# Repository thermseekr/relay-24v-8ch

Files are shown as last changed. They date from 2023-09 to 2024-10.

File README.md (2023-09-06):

# RELAY-24V-8CH

Relay board with 8x 24 VDC 10A relays. This board is designed to be used togheter with [ESP-24V-16CH](https://github.com/thermseekr/esp-24v-16ch) and [ESP-24V-32CH](https://github.com/thermseekr/esp-24v-32ch), but can be driven by any 24V control circuit compatible with NPN inputs.

The dimensions are such that the board can be mounted on a PCB DIN rail holder from the Brazilian manufacturer Metaltex, check [here](https://www.metaltex.com.br/produtos/componentes/suportes/sp7-suporte-para-montagem-de-placa-de-circuito-impresso-em-trilho-din) for details.

Board V1 uses Omron 16A relays and is limited to 12A/channel, board V2 uses Omron 10A relays and is limited to 8A/channel. The current limits are imposed per copper trace capacity.

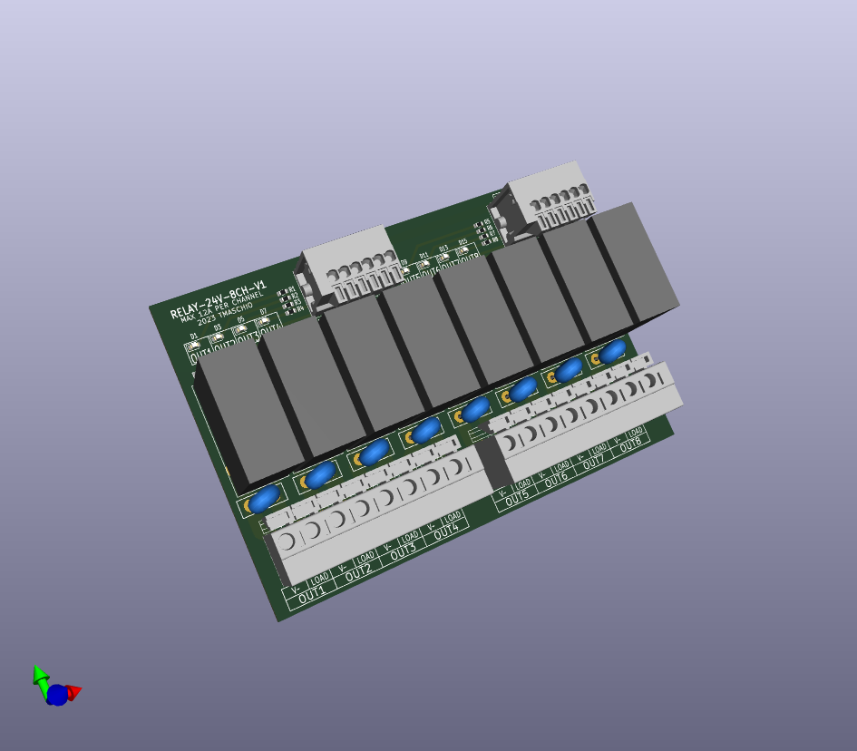
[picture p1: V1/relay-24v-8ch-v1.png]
RELAY-24V-8CH


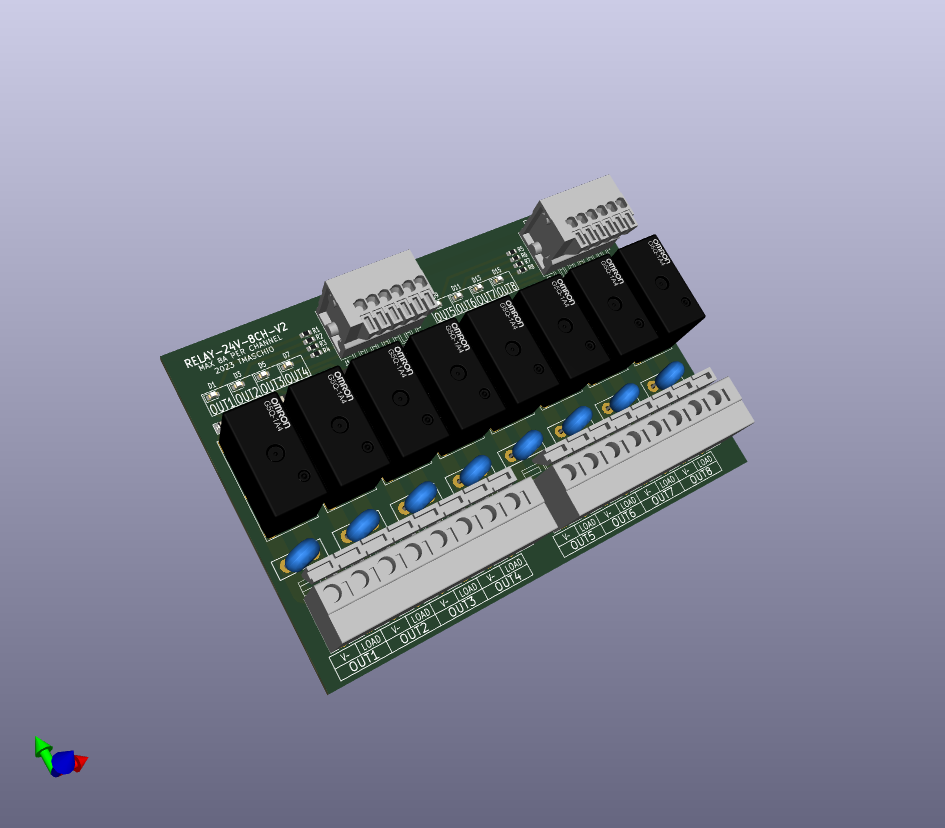
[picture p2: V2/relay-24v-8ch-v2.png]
RELAY-24V-8CH


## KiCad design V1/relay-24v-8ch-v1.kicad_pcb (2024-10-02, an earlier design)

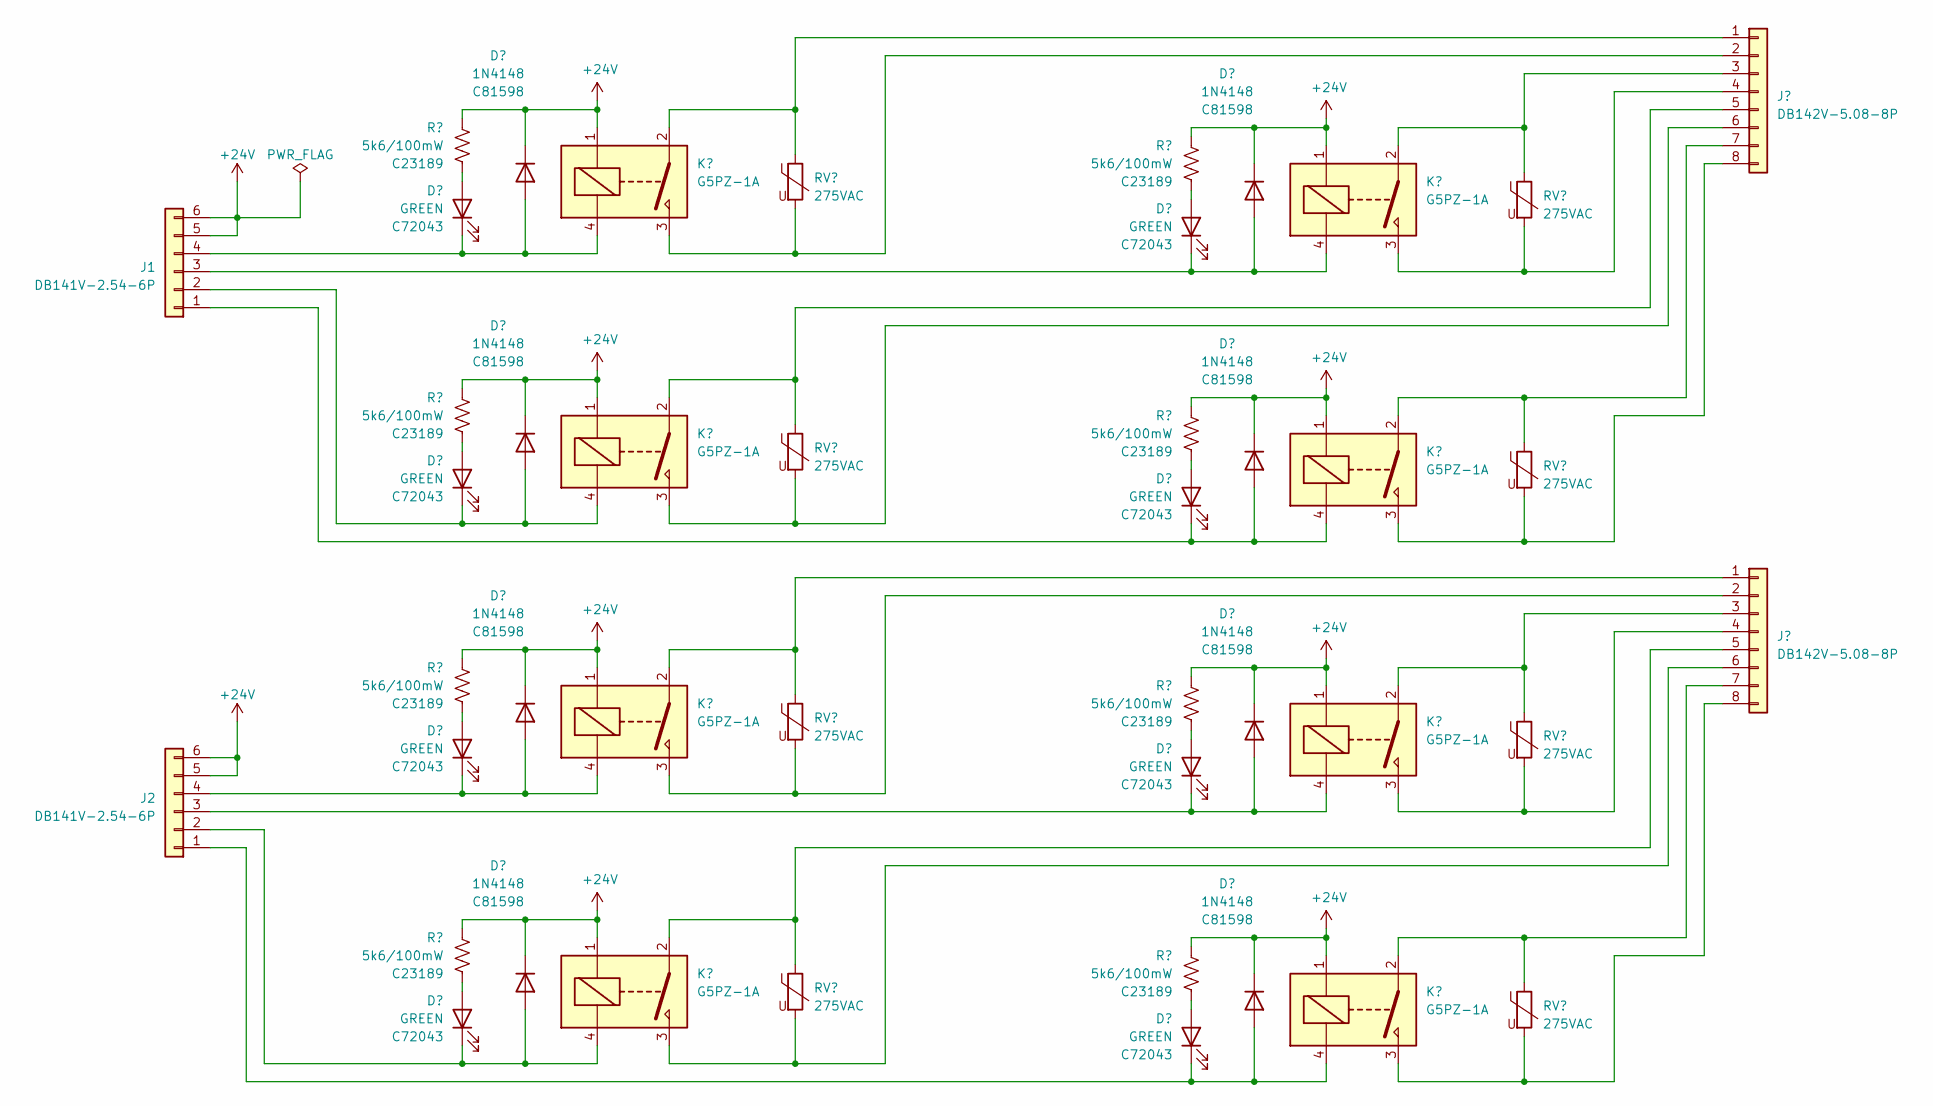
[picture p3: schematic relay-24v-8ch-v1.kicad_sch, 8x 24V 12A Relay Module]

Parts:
D1, D3, D5, D7, D9, D11, D13, D15: GREEN; LED_0603_1608Metric; Mfr PN 19-217/GHC-YR1S2/3T; LCSC Part # C72043
D2, D4, D6, D8, D10, D12, D14, D16: 1N4148; D_SOD-123; Mfr PN 1N4148W; LCSC Part # C81598
J1, J2: DB141V-2.54-6P; TerminalBlock_Dibo_DB141V-2.54-6P_1x06_P2.54mm_Vertical; Mfr PN DB141V-2.54-6P; JLCPCB BOM 1
J3, J4: DB142V-5.08-8P; TerminalBlock_Dibo_DB142V-5.08-8P_1x08_P5.08mm_Vertical; Mfr PN DB142V-5.08-8P; JLCPCB BOM 1
K1, K2, K3, K4, K5, K6, K7, K8: G5PZ-1A; Relay_SPST_Omron_G5PZ-1A; Mfr PN G5PZ-1A; JLCPCB BOM 0
R1, R2, R3, R4, R5, R6, R7, R8: 5k6/100mW; R_0603_1608Metric; Mfr PN 0603WAF5601T5E; LCSC Part # C23189
RV1, RV2, RV3, RV4, RV5, RV6, RV7, RV8: 275VAC; RV_Disc_D9.50mm_W3.6mm_P5.08mm; Mfr PN RM07D431KC1IE100; JLCPCB BOM 1

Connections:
+24V: D2.1 (K), D4.1 (K), D6.1 (K), D8.1 (K), D10.1 (K), D12.1 (K), D14.1 (K), D16.1 (K), J1.5, J1.6, J2.5, J2.6, K1.1, K2.1, K3.1, K4.1, K5.1, K6.1, K7.1, K8.1, R1.1, R2.1, R3.1, R4.1, R5.1, R6.1, R7.1, R8.1
unnamed: D1.2 (A), R1.2
unnamed: D1.1 (K), D2.2 (A), J1.4, K1.4
unnamed: D3.2 (A), R2.2
unnamed: D3.1 (K), D4.2 (A), J1.3, K2.4
unnamed: D5.2 (A), R3.2
unnamed: D5.1 (K), D6.2 (A), J1.2, K3.4
unnamed: D7.2 (A), R4.2
unnamed: D7.1 (K), D8.2 (A), J1.1, K4.4
unnamed: D9.2 (A), R5.2
unnamed: D9.1 (K), D10.2 (A), J2.4, K5.4
unnamed: D11.2 (A), R6.2
unnamed: D11.1 (K), D12.2 (A), J2.3, K6.4
unnamed: D13.2 (A), R7.2
unnamed: D13.1 (K), D14.2 (A), J2.2, K7.4
unnamed: D15.2 (A), R8.2
unnamed: D15.1 (K), D16.2 (A), J2.1, K8.4
unnamed: J3.1, K1.2, RV1.1
unnamed: J3.2, K1.3, RV1.2
unnamed: J3.3, K2.2, RV2.1
unnamed: J3.4, K2.3, RV2.2
unnamed: J3.5, K3.2, RV3.1
unnamed: J3.6, K3.3, RV3.2
unnamed: J3.7, K4.2, RV4.1
unnamed: J3.8, K4.3, RV4.2
unnamed: J4.1, K5.2, RV5.1
unnamed: J4.2, K5.3, RV5.2
unnamed: J4.3, K6.2, RV6.1
unnamed: J4.4, K6.3, RV6.2
unnamed: J4.5, K7.2, RV7.1
unnamed: J4.6, K7.3, RV7.2
unnamed: J4.7, K8.2, RV8.1
unnamed: J4.8, K8.3, RV8.2

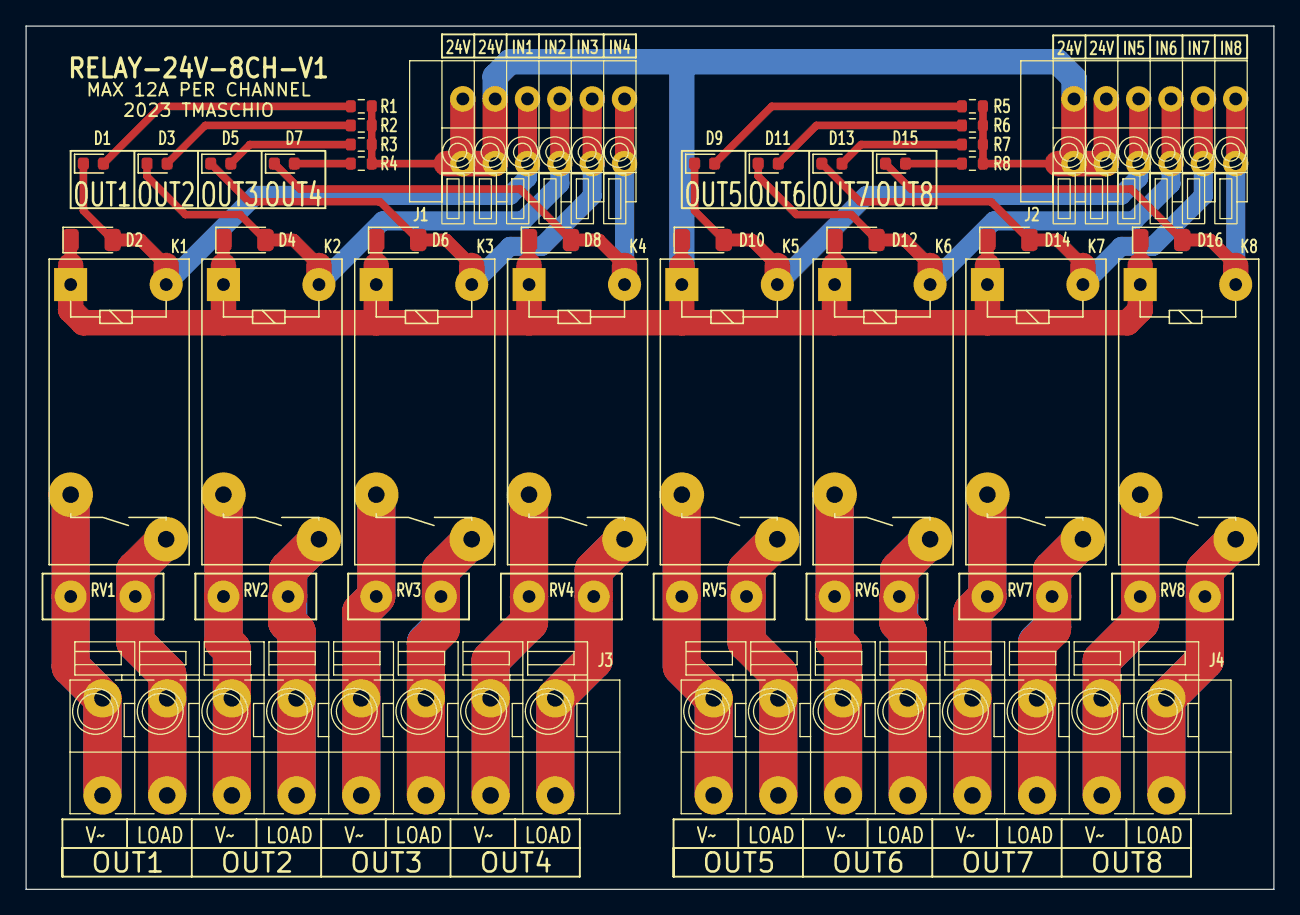
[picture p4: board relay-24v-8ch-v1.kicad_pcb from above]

Board: 2 copper layers, 98.0 x 67.8 mm, 44 parts (0 on the bottom side), 33 nets.

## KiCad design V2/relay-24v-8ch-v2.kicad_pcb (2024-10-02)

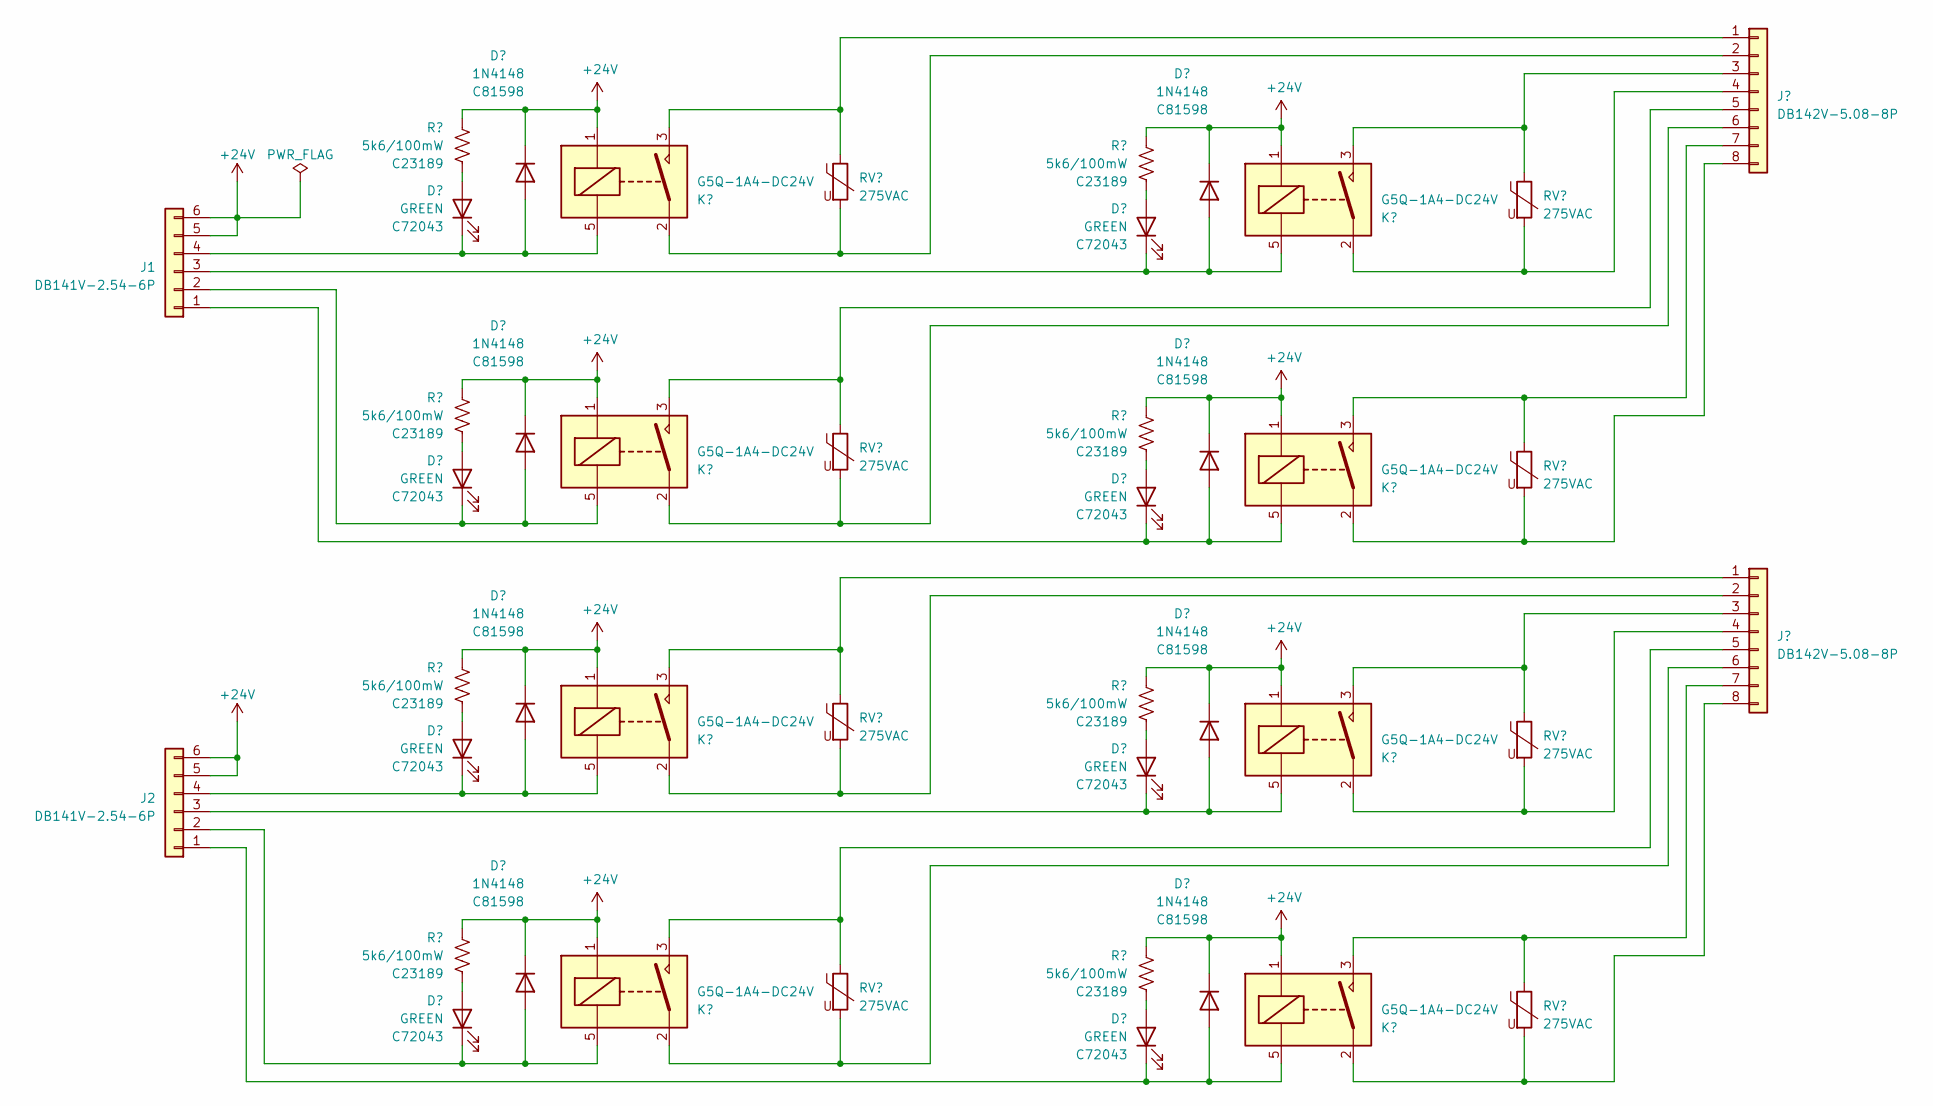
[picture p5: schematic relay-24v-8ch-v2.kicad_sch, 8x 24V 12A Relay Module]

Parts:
D1, D3, D5, D7, D9, D11, D13, D15: GREEN; LED_0603_1608Metric; Mfr PN 19-217/GHC-YR1S2/3T; LCSC Part # C72043
D2, D4, D6, D8, D10, D12, D14, D16: 1N4148; D_SOD-123; Mfr PN 1N4148W; LCSC Part # C81598
J1, J2: DB141V-2.54-6P; TerminalBlock_Dibo_DB141V-2.54-6P_1x06_P2.54mm_Vertical; Mfr PN DB141V-2.54-6P; JLCPCB BOM 1
J3, J4: DB142V-5.08-8P; TerminalBlock_Dibo_DB142V-5.08-8P_1x08_P5.08mm_Vertical; Mfr PN DB142V-5.08-8P; JLCPCB BOM 1
K1, K2, K3, K4, K5, K6, K7, K8: G5Q-1A4-DC24V; Relay_SPST_Omron-G5Q-1A; Mfr PN G5Q-1A4-DC24V; JLCPCB BOM 1
R1, R2, R3, R4, R5, R6, R7, R8: 5k6/100mW; R_0603_1608Metric; Mfr PN 0603WAF5601T5E; LCSC Part # C23189
RV1, RV2, RV3, RV4, RV5, RV6, RV7, RV8: 275VAC; RV_Disc_D9.50mm_W3.6mm_P5.08mm; Mfr PN RM07D431KC1IE100; JLCPCB BOM 1

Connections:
+24V: D2.1 (K), D4.1 (K), D6.1 (K), D8.1 (K), D10.1 (K), D12.1 (K), D14.1 (K), D16.1 (K), J1.5, J1.6, J2.5, J2.6, K1.1, K2.1, K3.1, K4.1, K5.1, K6.1, K7.1, K8.1, R1.1, R2.1, R3.1, R4.1, R5.1, R6.1, R7.1, R8.1
unnamed: D1.2 (A), R1.2
unnamed: D1.1 (K), D2.2 (A), J1.4, K1.5
unnamed: D3.2 (A), R2.2
unnamed: D3.1 (K), D4.2 (A), J1.3, K2.5
unnamed: D5.2 (A), R3.2
unnamed: D5.1 (K), D6.2 (A), J1.2, K3.5
unnamed: D7.2 (A), R4.2
unnamed: D7.1 (K), D8.2 (A), J1.1, K4.5
unnamed: D9.2 (A), R5.2
unnamed: D9.1 (K), D10.2 (A), J2.4, K5.5
unnamed: D11.2 (A), R6.2
unnamed: D11.1 (K), D12.2 (A), J2.3, K6.5
unnamed: D13.2 (A), R7.2
unnamed: D13.1 (K), D14.2 (A), J2.2, K7.5
unnamed: D15.2 (A), R8.2
unnamed: D15.1 (K), D16.2 (A), J2.1, K8.5
unnamed: J3.1, K1.3, RV1.1
unnamed: J3.2, K1.2, RV1.2
unnamed: J3.3, K2.3, RV2.1
unnamed: J3.4, K2.2, RV2.2
unnamed: J3.5, K3.3, RV3.1
unnamed: J3.6, K3.2, RV3.2
unnamed: J3.7, K4.3, RV4.1
unnamed: J3.8, K4.2, RV4.2
unnamed: J4.1, K5.3, RV5.1
unnamed: J4.2, K5.2, RV5.2
unnamed: J4.3, K6.3, RV6.1
unnamed: J4.4, K6.2, RV6.2
unnamed: J4.5, K7.3, RV7.1
unnamed: J4.6, K7.2, RV7.2
unnamed: J4.7, K8.3, RV8.1
unnamed: J4.8, K8.2, RV8.2

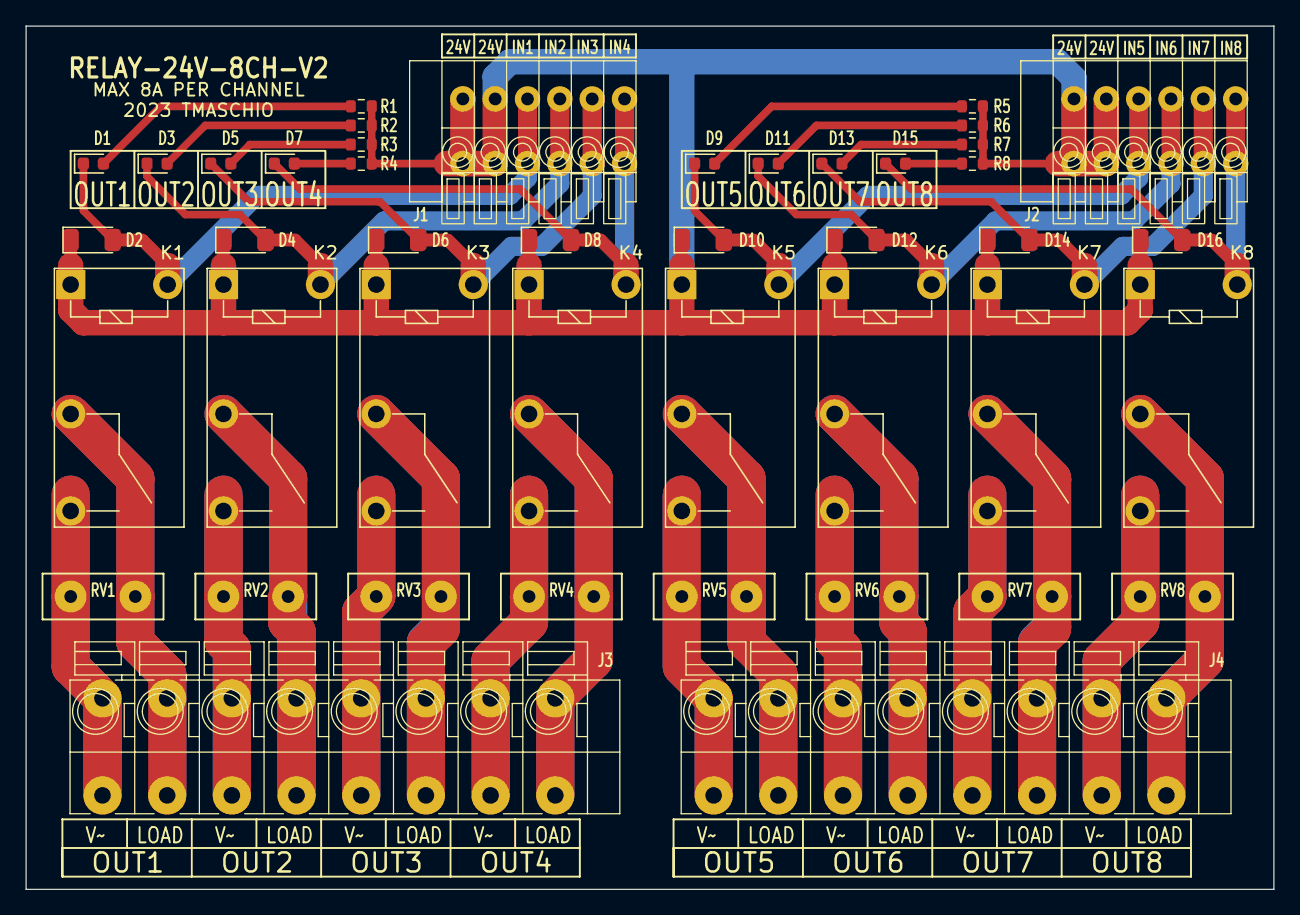
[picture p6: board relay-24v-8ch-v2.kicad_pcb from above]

Board: 2 copper layers, 98.0 x 67.8 mm, 44 parts (0 on the bottom side), 33 nets.

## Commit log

2023-05-21 Change connector 3D model
    [Relay-24v-8ch-V1.kicad_pcb, Relay-24v-8ch-V1.kicad_sch]
2023-05-21 Update silkscreen and board image.
    [Relay-24v-8ch-V1.kicad_pcb]
2023-05-22 Update to silkscreen and board image.
    [Relay-24v-8ch-V1.kicad_pcb, Relay-24v-8ch-V1.kicad_sch]
2023-05-22 Update board images
2023-05-22 Updates for fabrication
    [Relay-24v-8ch-V1.kicad_pcb]
2023-05-23 Adjustments for fabrication
    [Relay-24v-8ch-V1.kicad_pcb, Relay-24v-8ch-V1.kicad_sch]
2023-08-31 Varistor updated
    [Relay-24v-8ch-V1.kicad_sch]
2023-09-04 Redone everything
    [Relay-24v-8ch-V1-backup.kicad_pcb, Relay-24v-8ch-V2.kicad_pcb, Relay-24v-8ch-V2.kicad_sch]
2023-09-04 New board image
2023-09-06 Rename to lowercase
    [small-relay-24v-8ch-v1.kicad_pcb, small-relay-24v-8ch-v1.kicad_sch, small-relay-24v-8ch-v2.kicad_pcb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]
2024-10-02 Update to Kicad 8
    [relay-24v-8ch-v1.kicad_pcb, relay-24v-8ch-v1.kicad_sch, relay-24v-8ch-v2.kicad_pcb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]
